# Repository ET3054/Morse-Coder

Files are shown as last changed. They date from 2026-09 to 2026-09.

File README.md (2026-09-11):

# Morse-Coder

Kurs:                   ET3054 Entwurf und Fertigung von Flachbaugruppen

Jahrgang:               2024

Gruppe:                 8

Teilnehmer:             Hendrik Stadler, Jasper Martin Kyeck, Sebastian Gust

Projekt:                Morse-Coder

Beschreibung:           Eingabe von Morse-Code mit auditivem Feedback und Übersetzung auf LCD-Display, Eingabe von Buchstaben/Wörtern über Dreh-Encoder (Joystick) und Übersetzung als auditiven Sound in Morse-Code
                        mögliche Erweiterung -> Training und Übungen für Encoding und Decoding von Morse-Code

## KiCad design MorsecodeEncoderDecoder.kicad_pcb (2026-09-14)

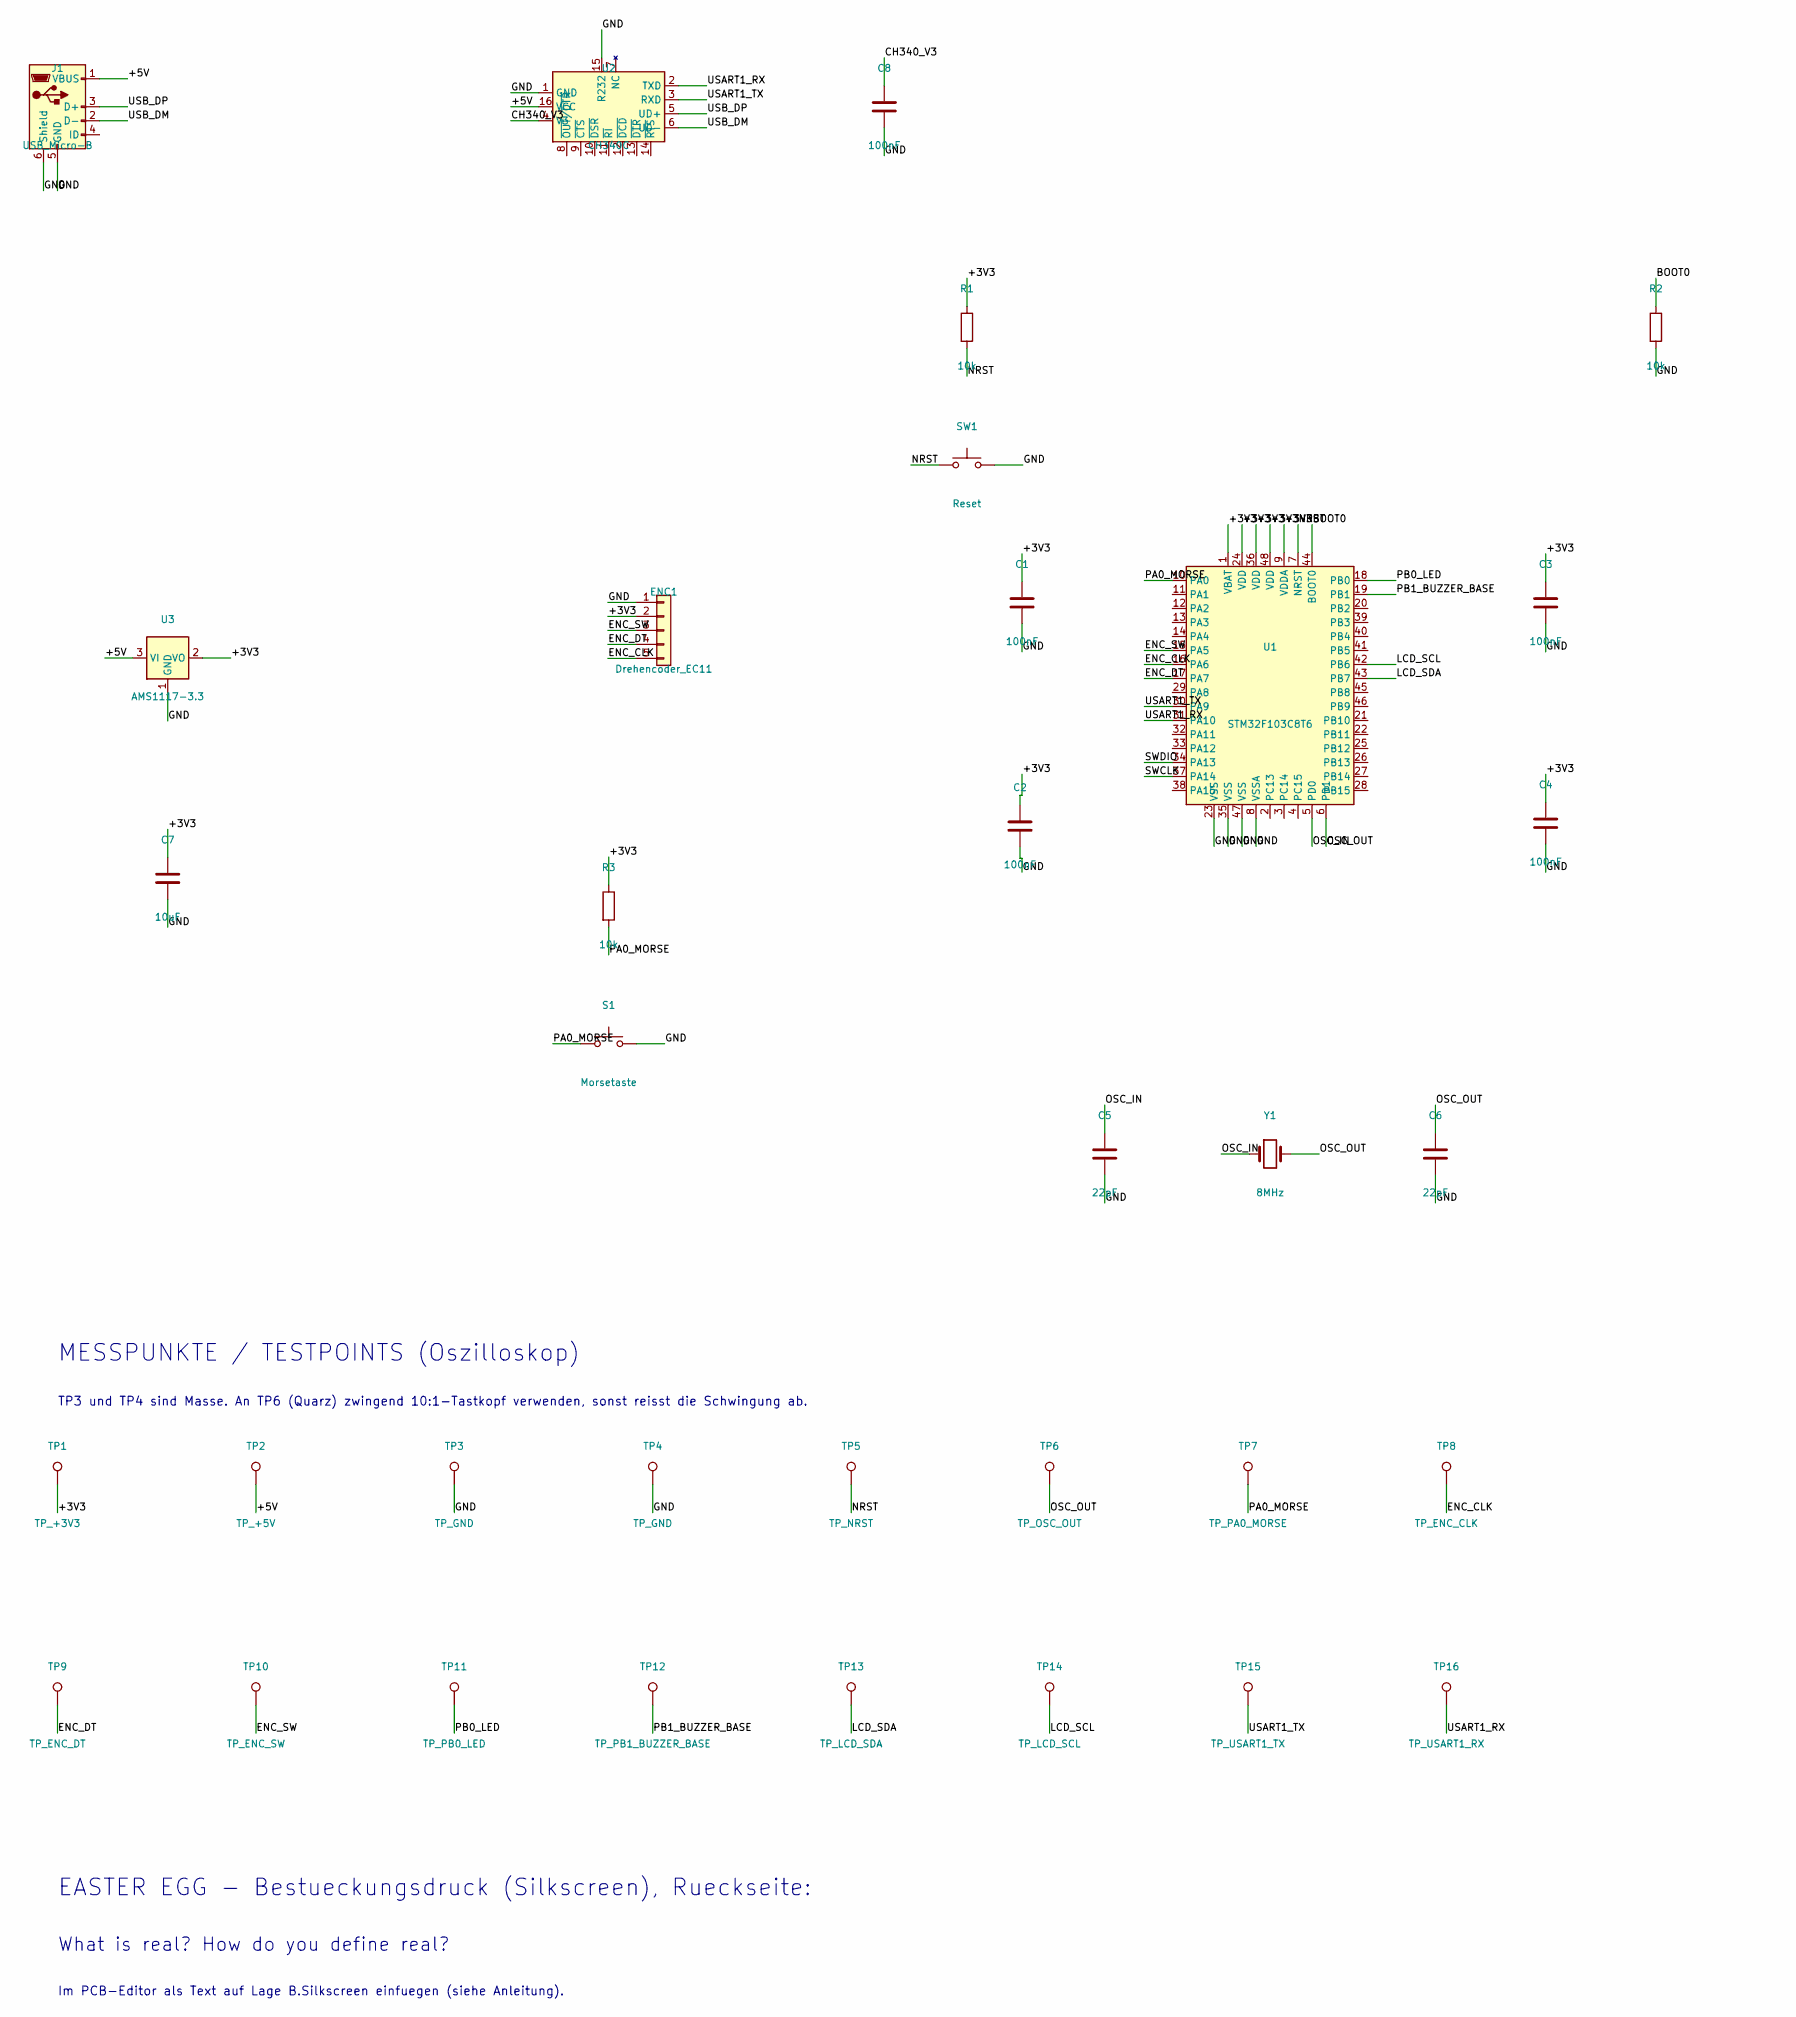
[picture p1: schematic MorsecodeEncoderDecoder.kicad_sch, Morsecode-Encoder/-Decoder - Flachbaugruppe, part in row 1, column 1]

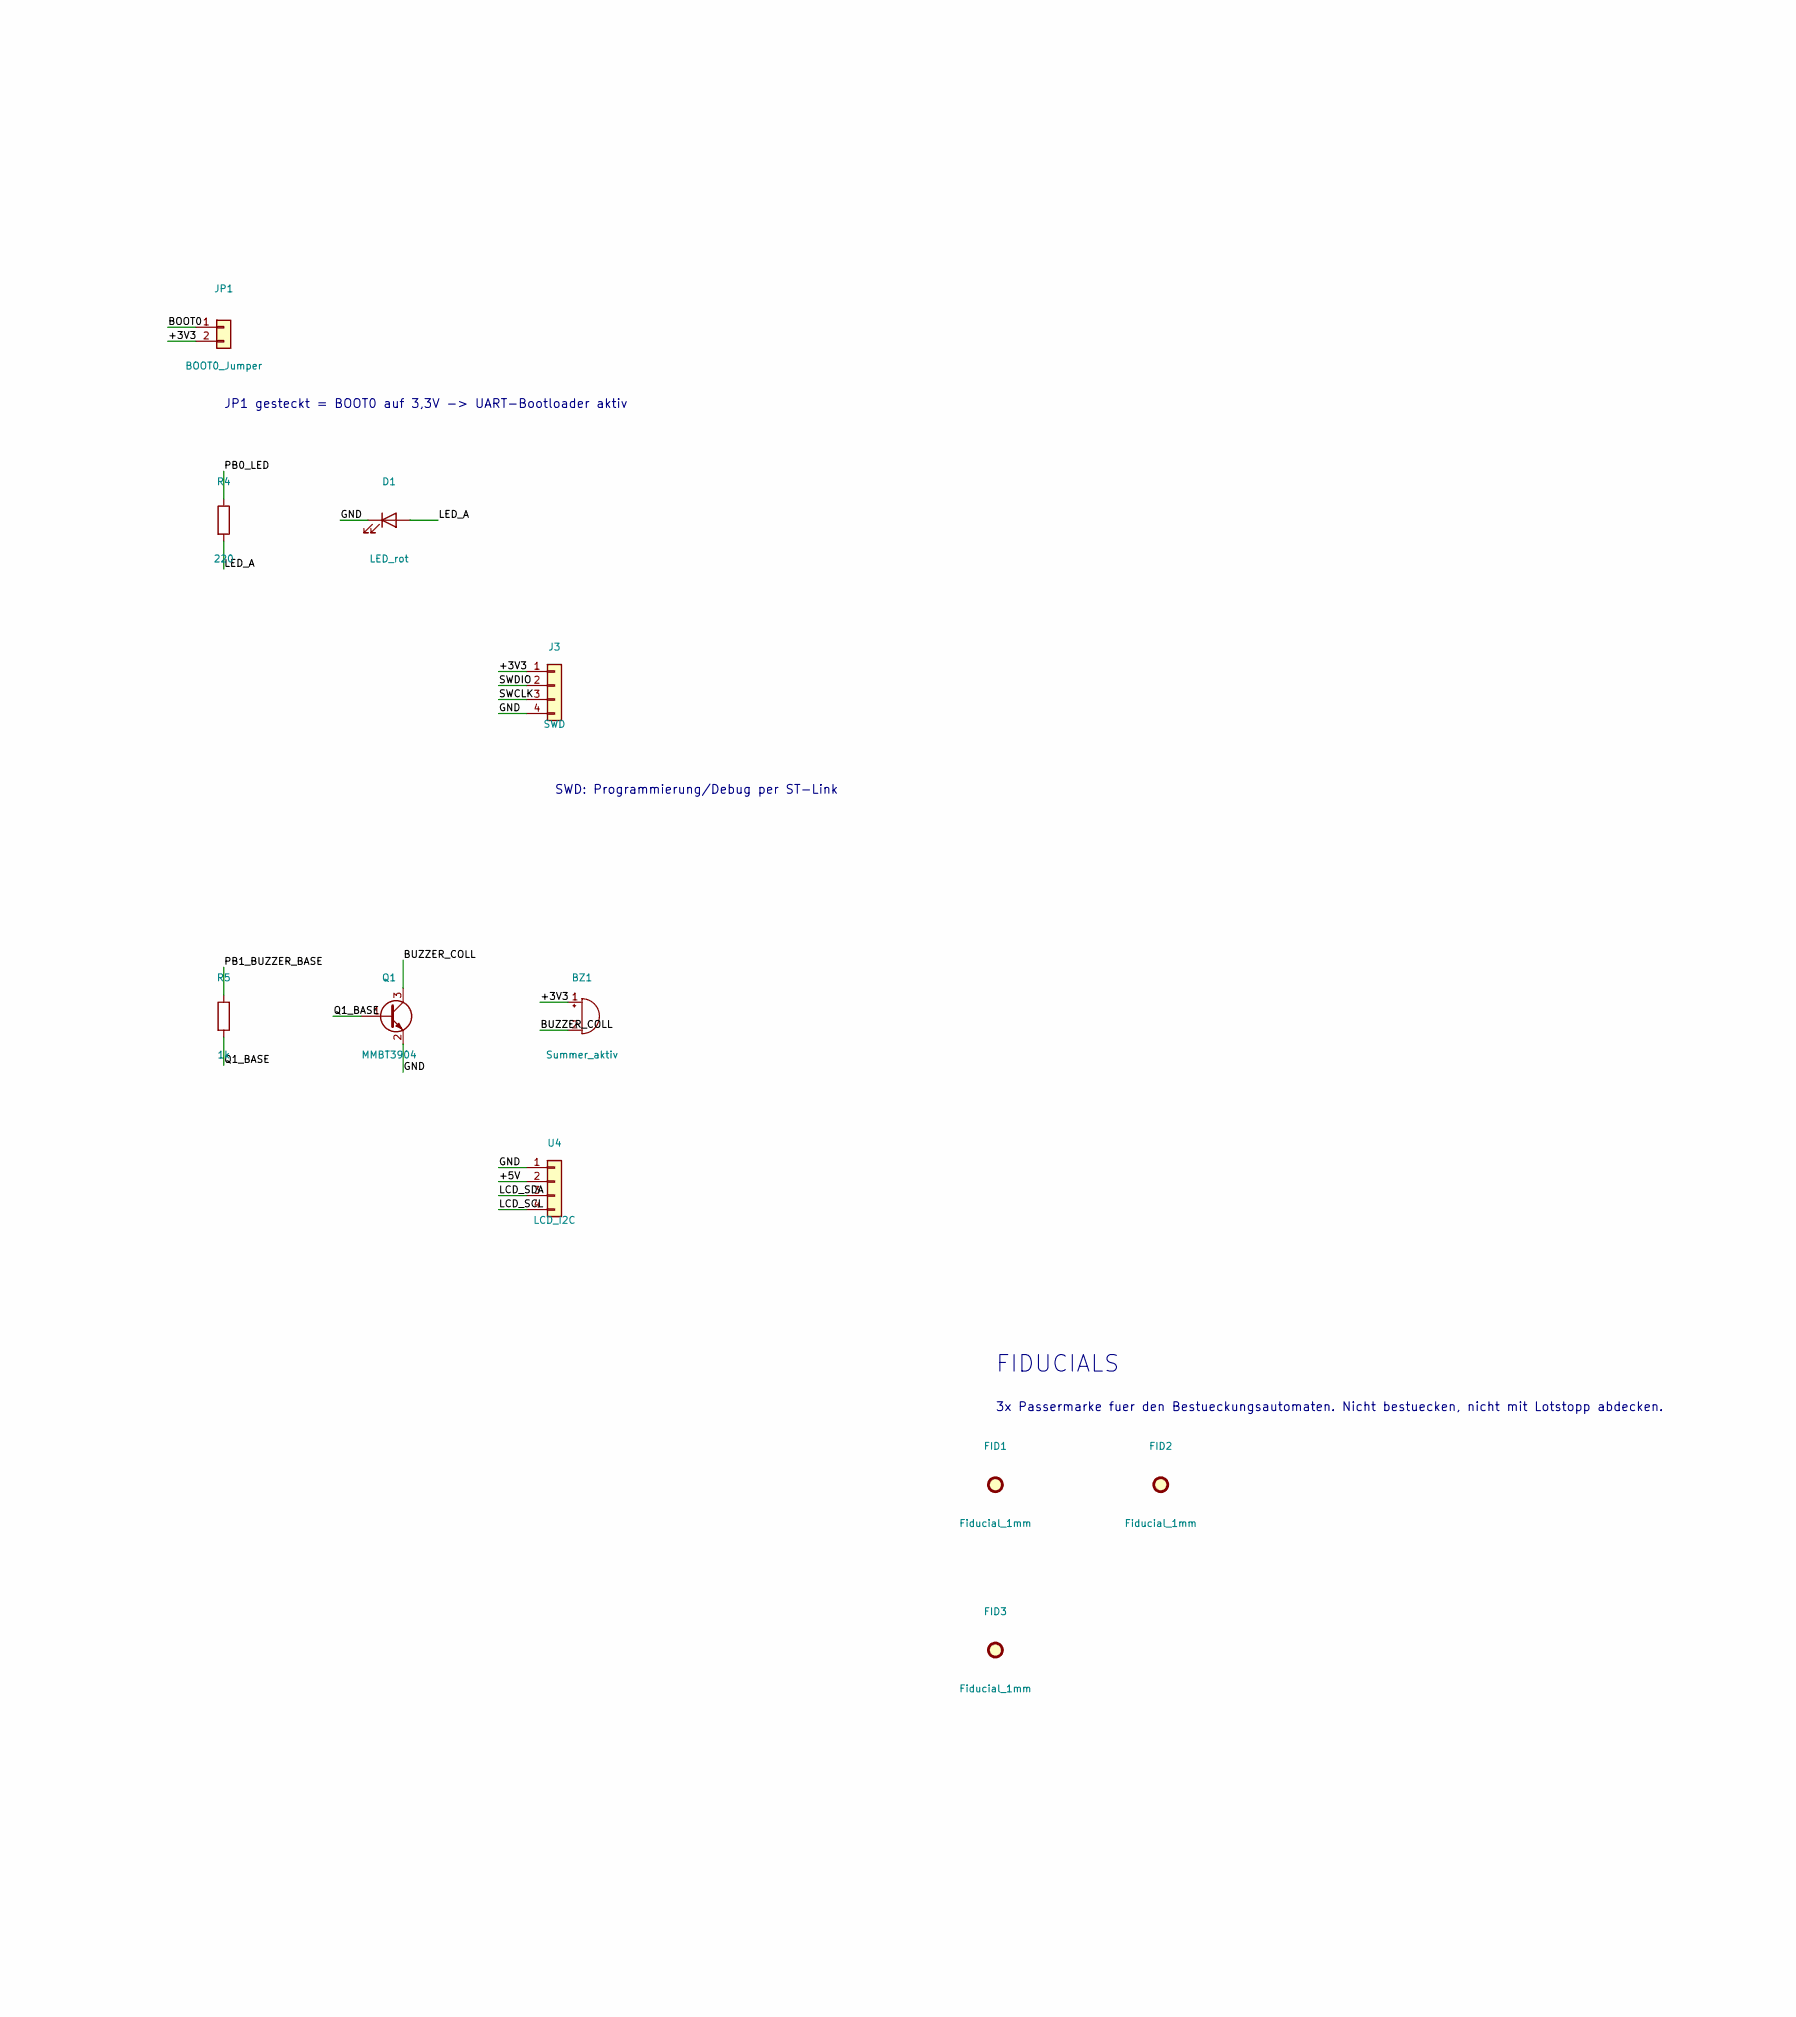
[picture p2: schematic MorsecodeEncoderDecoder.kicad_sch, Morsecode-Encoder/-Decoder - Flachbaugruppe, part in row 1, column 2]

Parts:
BZ1: Summer_aktiv; Buzzer_12x9.5RM7.6; LCSC PRUEFEN
C1, C2, C3, C4, C8: 100nF; C_0805_2012Metric; LCSC C49678
C5, C6: 22pF; C_0805_2012Metric; LCSC PRUEFEN
C7: 10uF; C_0805_2012Metric; LCSC C15850
D1: LED_rot; LED_0805_2012Metric; LCSC PRUEFEN
ENC1: Drehencoder_EC11; PinHeader_1x05_P2.54mm_Vertical; LCSC PRUEFEN
FID1, FID2, FID3: Fiducial_1mm; Fiducial_1mm_Mask2mm
J1: USB_Micro-B; USB_Micro-B_Molex-105017-0001; LCSC PRUEFEN
J3: SWD; PinHeader_1x04_P2.54mm_Vertical; LCSC PRUEFEN
JP1: BOOT0_Jumper; PinHeader_1x02_P2.54mm_Vertical; LCSC PRUEFEN
Q1: MMBT3904; SOT-23; LCSC PRUEFEN
R1, R2, R3: 10k; R_0805_2012Metric; LCSC C17414
R4: 220; R_0805_2012Metric; LCSC PRUEFEN
R5: 1k; R_0805_2012Metric; LCSC PRUEFEN
S1: Morsetaste; SW_SPST_TL3342; LCSC PRUEFEN
SW1: Reset; SW_SPST_TL3342; LCSC PRUEFEN
TP1: TP_+3V3; TestPoint_Pad_D1.5mm
TP2: TP_+5V; TestPoint_Pad_D1.5mm
TP3, TP4: TP_GND; TestPoint_Pad_D1.5mm
TP5: TP_NRST; TestPoint_Pad_D1.5mm
TP6: TP_OSC_OUT; TestPoint_Pad_D1.5mm
TP7: TP_PA0_MORSE; TestPoint_Pad_D1.5mm
TP8: TP_ENC_CLK; TestPoint_Pad_D1.5mm
TP9: TP_ENC_DT; TestPoint_Pad_D1.5mm
TP10: TP_ENC_SW; TestPoint_Pad_D1.5mm
TP11: TP_PB0_LED; TestPoint_Pad_D1.5mm
TP12: TP_PB1_BUZZER_BASE; TestPoint_Pad_D1.5mm
TP13: TP_LCD_SDA; TestPoint_Pad_D1.5mm
TP14: TP_LCD_SCL; TestPoint_Pad_D1.5mm
TP15: TP_USART1_TX; TestPoint_Pad_D1.5mm
TP16: TP_USART1_RX; TestPoint_Pad_D1.5mm
U1: STM32F103C8T6; LQFP-48_7x7mm_P0.5mm; LCSC C8734
U2: CH340C; SOIC-16_3.9x9.9mm_P1.27mm; LCSC C84681
U3: AMS1117-3.3; SOT-223-3_TabPin2; LCSC C6186
U4: LCD_I2C; PinHeader_1x04_P2.54mm_Vertical; LCSC PRUEFEN
Y1: 8MHz; Crystal_SMD_3225-4Pin_3.2x2.5mm; LCSC PRUEFEN

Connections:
/+3V3: BZ1.1 (+), C1.1, C2.1, C3.1, C4.1, C7.1, ENC1.2, J3.1, JP1.2, R1.1, R3.1, TP1.1 (1_1), U1.1 (VBAT), U1.9 (VDDA), U1.24 (VDD), U1.36 (VDD), U1.48 (VDD), U3.2 (VO)
/+5V: J1.1 (VBUS), TP2.1 (1_1), U2.16 (VCC), U3.3 (VI), U4.2
/BOOT0: JP1.1, R2.1, U1.44 (BOOT0)
/BUZZER_COLL: BZ1.2 (-), Q1.3 (C)
/CH340_V3: C8.1, U2.4 (V3)
/ENC_CLK: ENC1.5, TP8.1 (1_1), U1.16 (PA6)
/ENC_DT: ENC1.4, TP9.1 (1_1), U1.17 (PA7)
/ENC_SW: ENC1.3, TP10.1 (1_1), U1.15 (PA5)
/GND: C1.2, C2.2, C3.2, C4.2, C5.2, C6.2, C7.2, C8.2, D1.1 (K), ENC1.1, J1.5 (GND), J1.6 (Shield), J3.4, Q1.2 (E), R2.2, S1.2, SW1.2, TP3.1 (1_1), TP4.1 (1_1), U1.8 (VSSA), U1.23 (VSS), U1.35 (VSS), U1.47 (VSS), U2.1 (GND), U2.15 (R232), U3.1 (GND), U4.1
/LCD_SCL: TP14.1 (1_1), U1.42 (PB6), U4.4
/LCD_SDA: TP13.1 (1_1), U1.43 (PB7), U4.3
/LED_A: D1.2 (A), R4.2
/NRST: R1.2, SW1.1, TP5.1 (1_1), U1.7 (NRST)
/OSC_IN: C5.1, U1.5 (PD0), Y1.1
/OSC_OUT: C6.1, TP6.1 (1_1), U1.6 (PD1), Y1.2
/PA0_MORSE: R3.2, S1.1, TP7.1 (1_1), U1.10 (PA0)
/PB0_LED: R4.1, TP11.1 (1_1), U1.18 (PB0)
/PB1_BUZZER_BASE: R5.1, TP12.1 (1_1), U1.19 (PB1)
/Q1_BASE: Q1.1 (B), R5.2
/SWCLK: J3.3, U1.37 (PA14)
/SWDIO: J3.2, U1.34 (PA13)
/USART1_RX: TP16.1 (1_1), U1.31 (PA10), U2.2 (TXD)
/USART1_TX: TP15.1 (1_1), U1.30 (PA9), U2.3 (RXD)
/USB_DM: J1.2 (D-), U2.6 (UD-)
/USB_DP: J1.3 (D+), U2.5 (UD+)

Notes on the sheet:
What is real? How do you define real?
MESSPUNKTE / TESTPOINTS (Oszilloskop)
3x Passermarke fuer den Bestueckungsautomaten. Nicht bestuecken, nicht mit Lotstopp abdecken.
SWD: Programmierung/Debug per ST-Link
EASTER EGG - Bestueckungsdruck (Silkscreen), Rueckseite:
JP1 gesteckt = BOOT0 auf 3,3V -> UART-Bootloader aktiv
TP3 und TP4 sind Masse. An TP6 (Quarz) zwingend 10:1-Tastkopf verwenden, sonst reisst die Schwingung ab.
Im PCB-Editor als Text auf Lage B.Silkscreen einfuegen (siehe Anleitung).
FIDUCIALS

Board: 2 copper layers, 46 parts (0 on the bottom side), 25 nets, no tracks yet.
